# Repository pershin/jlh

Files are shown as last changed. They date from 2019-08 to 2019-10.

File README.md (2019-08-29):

# JLH
Усилитель JLH на отечественных транзисторах (КТ361Г, КТ801А и 2Т803А)

## Технические параметры
Количество каналов: 2\
Напряжение питания: 12... 17В\
Сопротивление нагрузки: 4 Ω

## Электронные компоненты

### Транзисторы биполярные
Наименование | Кол-во
--- | :---:
КТ361Г | 2
КТ801А | 2
2Т803А | 4

### Конденсаторы
Наименование | Кол-во
--- | :---:
0,1 мкФ 250 В | 2
KZK White Line 2,2 мкФ 250 В 5% | 2
Epcos 100 мкФ 50 В | 2
Nichicon KZ 50V 220 uF | 2
Epcos 470 мкФ 25 В | 2
2200 мкФ 50 В | 2
Nichicon FW 35V 4700 uF | 2

### Резисторы
Наименование | Кол-во
--- | :---:
47 Ω 0,5 Вт | 2
Р1-7 180 Ω 2 Вт ±10% | 2
ОМЛТ-0,5 220 Ω ±5% | 2
ОМЛТ-0,5 2,2 кОм ±5% | 2
ОМЛТ-0,5 2,7 кОм ±5% | 2
МЛТ-0,5 8,2 кОм ±5% | 2
ОМЛТ-0,5 39 кОм ±5% | 2
МЛТ-0,5 100 кОм ±5% | 4

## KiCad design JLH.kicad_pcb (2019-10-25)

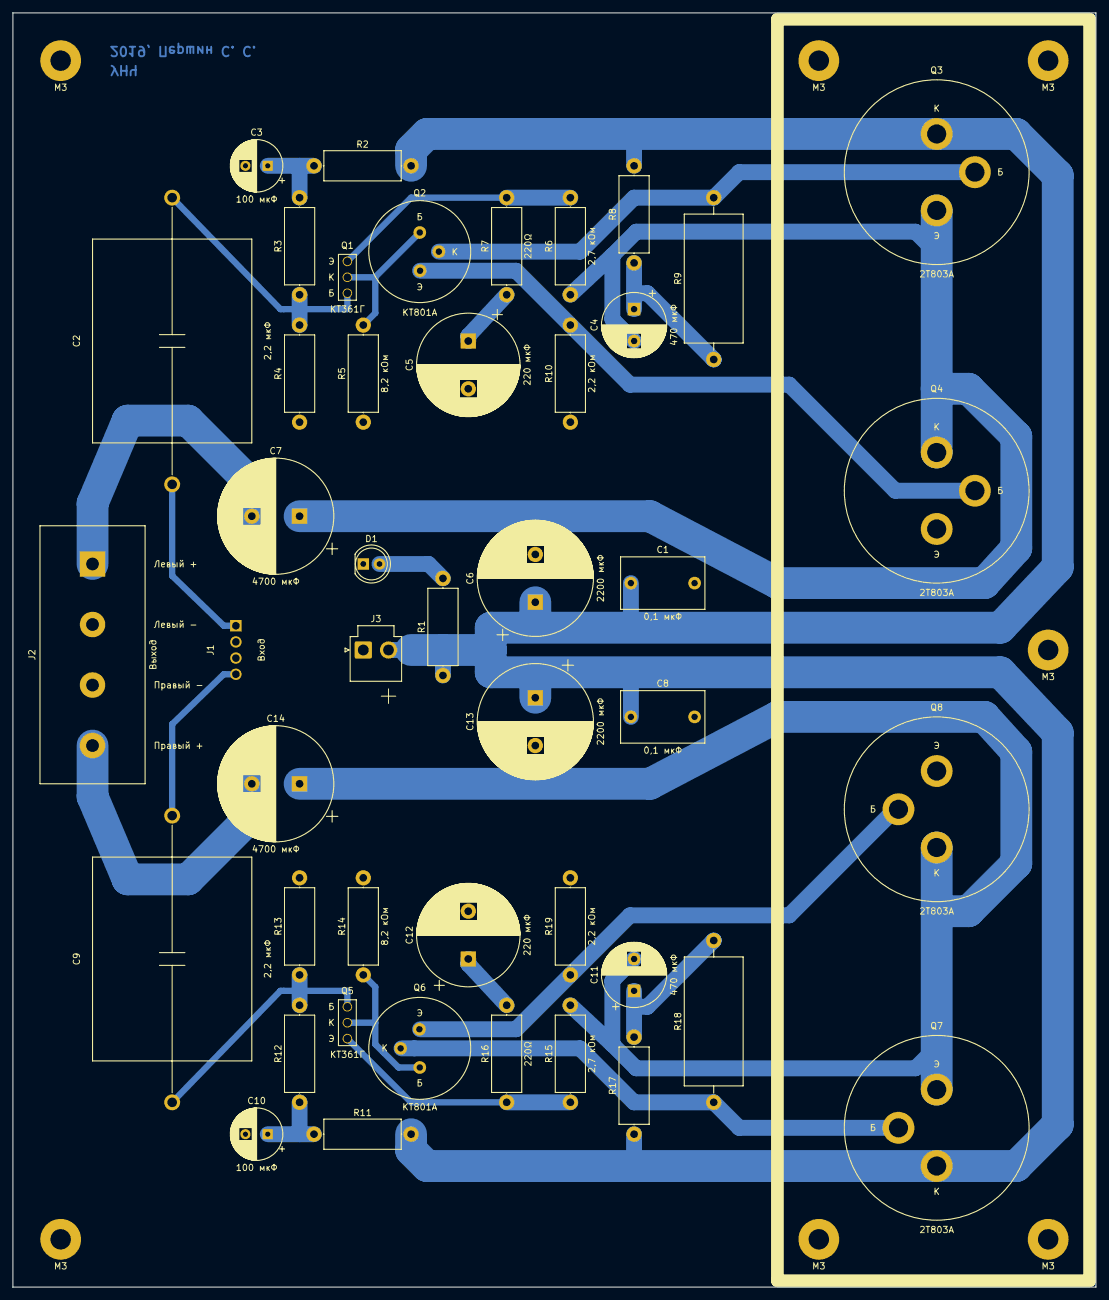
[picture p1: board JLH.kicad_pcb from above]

Board: 2 copper layers, 170.0 x 200.0 mm, 52 parts (0 on the bottom side), 25 nets.

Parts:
C1, C8: 0,1 мкФ; C_Rect_L13.0mm_W8.0mm_P10.00mm_FKS3_FKP3_MKS4
C2, C9: 2,2 мкФ; KZK_White_Line_L32.0mm_D25.0mm_P45.00mm_Horizontal
C3, C10: 100 мкФ; CP_Radial_D8.0mm_P3.50mm
C4, C11: 470 мкФ; CP_Radial_D10.0mm_P5.00mm
C5, C12: 220 мкФ; CP_Radial_D16.0mm_P7.50mm
C6, C13: 2200 мкФ; CP_Radial_D18.0mm_P7.50mm
C7, C14: 4700 мкФ; CP_Radial_D18.0mm_P7.50mm
D1: LED; LED_D5.0mm
H1, H2, H3, H4, H5, H6, H7: M3; MountingHole_3.2mm_M3_Pad
J1: Вход; 5-103639-3
J2: Выход; T34-BM11-04
J3: B2P-VH; JST_VH_B2P-VH_1x02_P3.96mm_Vertical
Q1, Q5: КТ361Г; kt-13
Q2, Q6: КТ801А; kt801
Q3, Q4, Q7, Q8: 2Т803А; 2t803a
R1, R10, R19: 2,2 кОм; R_Axial_DIN0414_L11.9mm_D4.5mm_P15.24mm_Horizontal
R2, R11: 39 кОм; R_Axial_DIN0414_L11.9mm_D4.5mm_P15.24mm_Horizontal
R3, R4, R12, R13: 100 кОм; R_Axial_DIN0414_L11.9mm_D4.5mm_P15.24mm_Horizontal
R5, R14: 8,2 кОм; R_Axial_DIN0414_L11.9mm_D4.5mm_P15.24mm_Horizontal
R6, R15: 2,7 кОм; R_Axial_DIN0414_L11.9mm_D4.5mm_P15.24mm_Horizontal
R7, R16: 220Ω; R_Axial_DIN0414_L11.9mm_D4.5mm_P15.24mm_Horizontal
R8, R17: 47Ω; R_Axial_DIN0414_L11.9mm_D4.5mm_P15.24mm_Horizontal
R9, R18: 180Ω; R_Axial_DIN0922_L20.0mm_D9.0mm_P25.40mm_Horizontal

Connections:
/Левый канал/IN+: C2.1, J1.1
/Левый канал/OUT+: C7.2, J2.1
/Левый канал/VCC: C1.1, C6.1, C8.1, C13.1, J3.2, Q3.1, Q7.1, R1.1, R2.1, R8.1, R11.1, R17.1
/Правый канал/IN+: C9.1, J1.4
/Правый канал/OUT+: C14.2, J2.4
GND: C1.2, C3.2, C5.2, C6.2, C8.2, C10.2, C12.2, C13.2, D1.1, J1.2, J1.3, J2.2, J2.3, J3.1, Q4.3, Q8.3, R4.2, R5.2, R10.2, R13.2, R14.2, R19.2
unnamed: C2.2, Q1.3, R3.2, R4.1
unnamed: C3.1, R2.2, R3.1
unnamed: C4.1, R8.2, R9.2
unnamed: C4.2, C7.1, Q3.3, Q4.1, R6.2
unnamed: C5.1, R7.2
unnamed: C9.2, Q5.3, R12.2, R13.1
unnamed: C10.1, R11.2, R12.1
unnamed: C11.1, R17.2, R18.2
unnamed: C11.2, C14.1, Q7.3, Q8.1, R15.2
unnamed: C12.1, R16.2
unnamed: D1.2, R1.2
unnamed: Q1.1, R6.1, R7.1
unnamed: Q1.2, Q2.1, R5.1
unnamed: Q2.2, Q3.2, R9.1
unnamed: Q2.3, Q4.2, R10.1
unnamed: Q5.1, R15.1, R16.1
unnamed: Q5.2, Q6.1, R14.1
unnamed: Q6.2, Q7.2, R18.1
unnamed: Q6.3, Q8.2, R19.1

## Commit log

2019-05-16 Updated paths to 3d models
    [JLH.kicad_pcb]
2019-05-16 Removed potentiometer
    [JLH.sch]
2019-05-19 Added 2T803A
    [JLH.kicad_pcb, JLH.sch]
2019-05-19 Update 2T803A
    [JLH.kicad_pcb, JLH.sch]
2019-05-19 Added 3d model for 2T803A
    [JLH.kicad_pcb]
2019-06-07 Assigned footprints for capacitors
    [JLH.sch]
2019-06-07 Assigned footprint for power connector
    [JLH.sch]
2019-06-08 Updated resistors
    [JLH.sch]
2019-06-10 Updated PCB (one channel)
    [JLH.kicad_pcb, JLH.sch]
2019-06-15 Added I/O terminals
    [JLH.kicad_pcb, JLH.sch]
2019-06-15 Added scheme for 2 channel (stereo)
    [JLH.sch]
2019-06-21 Added hierarchical sheet for L/R channels
    [JLH.sch, OneChannel.sch]
2019-06-21 New annotation
    [JLH.sch, OneChannel.sch]
2019-07-06 Updated PCB
    [JLH.kicad_pcb, JLH.sch, OneChannel.sch]
2019-07-15 Added filled zones
    [JLH.kicad_pcb]
2019-07-17 Added mounting holes
    [JLH.kicad_pcb, JLH.sch]
2019-08-29 Added capacitors
    [JLH.kicad_pcb, OneChannel.sch]
2019-10-21 Fixed polarity
    [JLH.kicad_pcb, JLH.sch]
2019-10-22 Removed top layer
    [JLH.kicad_pcb]
2019-10-22 Added author to PCB
    [JLH.kicad_pcb, JLH.sch, OneChannel.sch]
2019-10-23 Updated output directory
    [JLH.kicad_pcb]
2019-10-24 Fixed GND
    [JLH.kicad_pcb]
2019-10-24 Added mounting hole
    [JLH.kicad_pcb, JLH.sch]
2019-10-25 Created gerber and drill files
    [JLH-B_Cu.gbr, JLH-B_Mask.gbr, JLH-B_Paste.gbr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]
